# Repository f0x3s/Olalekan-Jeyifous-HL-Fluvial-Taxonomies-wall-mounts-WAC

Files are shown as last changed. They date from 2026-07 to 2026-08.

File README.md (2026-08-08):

# Olalekan Jeyifous Fluvial Taxonomies Wall Mounts

<p align="center">
  batch of mounts epoxied to sculptures
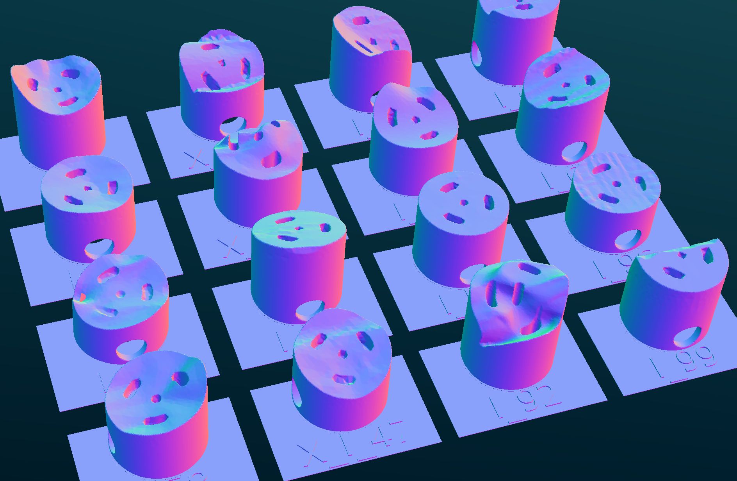
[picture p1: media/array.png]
array of processed mount meshes
  
</p>

A programmatic approach to generating 40 unique wall mounts for Olekelan Jeyifous' sculpture series: *Fluvial Taxonomies* as part of [*Hydrocosmic Litanies*](https://www.walkerart.org/whats-on/olalekan-jeyifous-hydricosmic-litanies/), his solo exhibition at the Walker Art Center.

This repository contains the editable mount files with their exported meshes, final print-ready STLs, and the batch-processing workflow used to center, identify, thermally compensate, and repair each mount before printing.

*__This repository does not contain any artwork meshes or original artist files__*

## Files
Fabrication files and processing tools for the wall-mount system.
> 📂 **[3d-files](3d-files)/** — *source mount geometry*<br>
> - 📁 [`isolated-mount-meshmixer`](3d-files/isolated-mount-meshmixer)/ — *editable Meshmixer project files*
> - 📁 [`isolated-mount-export`](3d-files/isolated-mount-export)/ — *exported STL files used as processing inputs*
>
> 📂 **[ready-for-print](ready-for-print)/** — *processed and repaired print files*<br>
> - 📁 [`printed`](ready-for-print/printed)/ — *completed mounts retained for print tracking*
> - 🧊 [`insert.stl`](ready-for-print/insert.stl) — *generated insert puck*
>
> 📂 **[scripts](scripts)/** — *Python and OpenSCAD processing tools*<br>
> - 🐍 [`batch_process_ft_mounts.py`](scripts/batch_process_ft_mounts.py) — *main batch-processing script*
> - ⚙️ [`batch_openscad.scad`](scripts/batch_openscad.scad) — *combined label and thermal-compensation operation*
> - ⚙️ [`generate_label.scad`](scripts/generate_label.scad) — *standalone label generator used by the fallback process*
> - ⚙️ [`label_module.scad`](scripts/label_module.scad) — *label and brim geometry*
> - ⚙️ [`thermal_expansion_ring.scad`](scripts/thermal_expansion_ring.scad) — *thermal-expansion compensation cutting geometry*
> - ⚙️ [`insert.scad`](scripts/insert.scad) — *insert puck geometry*

## Background and File Preproduction

Installing *Fluvial Taxonomies* presented several technical challenges. The resin-printed sculptures are fragile, with highly detailed surfaces and no preordained mounting points nor provisions for hardware. The piece is intended to be shown as groupings of objects mounted offset from the walls in the gallery. I determined that the best way to hang them was a custom 3d-printed mount per-object, secured to the sculpture with specialty plastic epoxy. These mounts are created from duplicates of a standard base geometry, pictured below, that each have a sculpture digitally subtracted from them:

<p align="center">
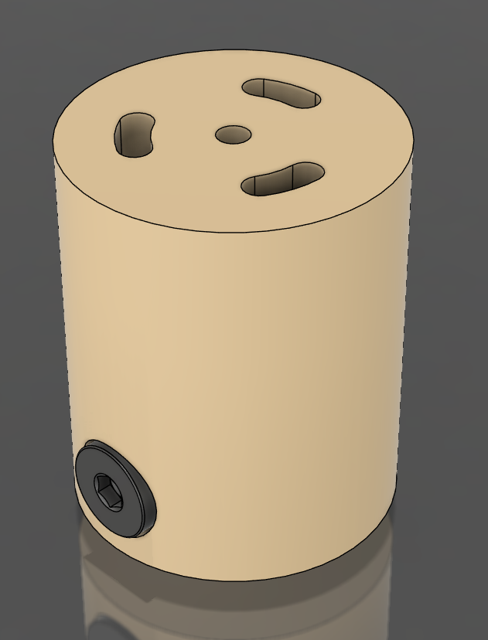
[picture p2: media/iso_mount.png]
iso view of base mount geometry
  
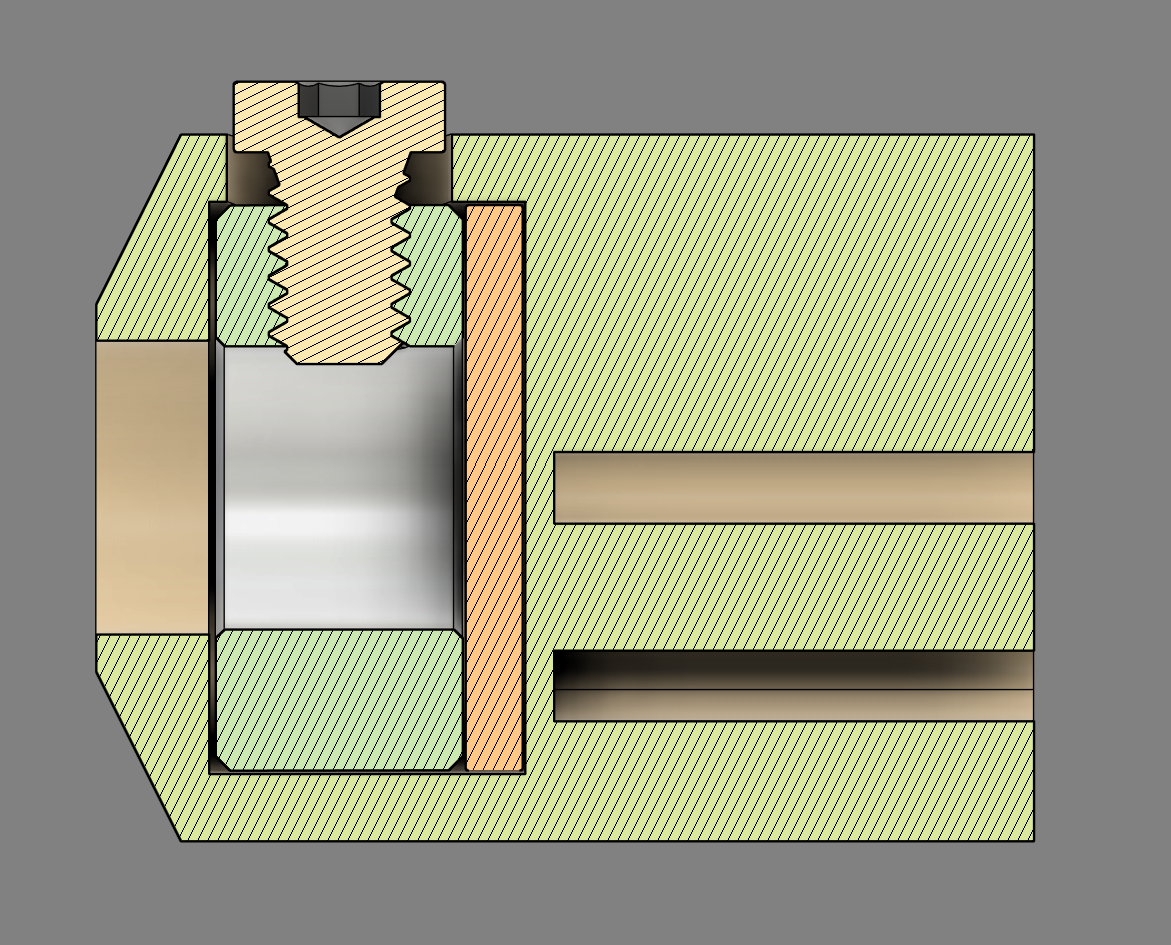
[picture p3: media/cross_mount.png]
base mount geometry cross sectional analysis
  
</p>

The inserted shaft collar *([McMaster: 9946K15](https://www.mcmaster.com/9946K15/))* allows for strong coupling to wall-mounted rods, and the low-profile machine screw *([McMaster: 92220A182](https://www.mcmaster.com/92220A182/))* arrests rotation inside the mount. The axial channels provide space for epoxy to seep into the structure for a mechanically strong bond.

<p align="center">
  recording physical dimensions asst. Prerna
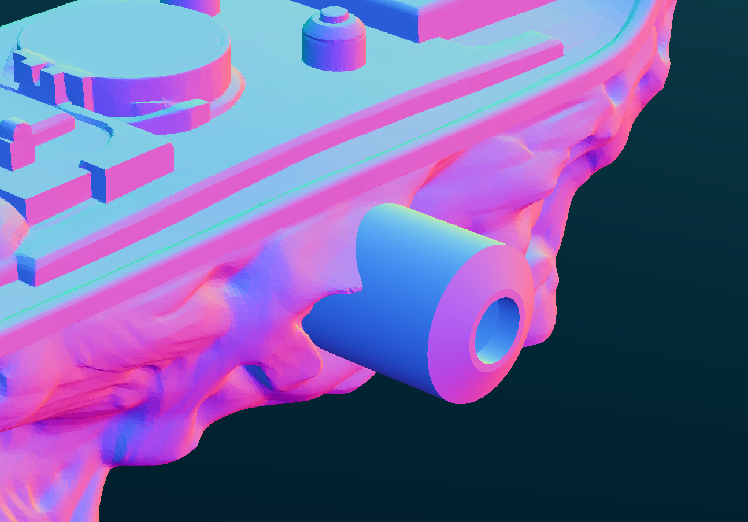
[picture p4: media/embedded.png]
mount geometry embedded in sculpture mesh
  
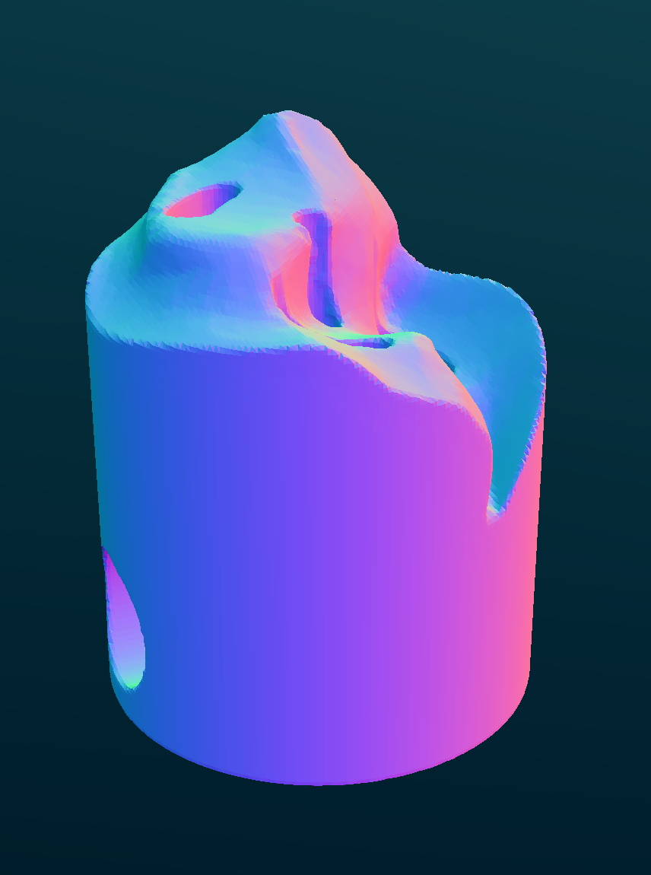
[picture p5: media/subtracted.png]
sculpture mesh subtracted from mount geometry
  
</p>

The next step was to scale the sculpture models, virtually place the mounts, and perform the Boolean operations. The artist-provided sculpture mesh files were not consistently scaled, so an extent measurement was taken from the physical piece and used to correctively transform the file. Then, a copy of the mount geometry was manually oriented against it, with as much of the region beyond the start of the epoxy channels intersecting the sculpture geometry as possible. The sculpture was subtracted from the mount, and the mount was re-oriented axially along the z-axis (without regard to its position in world space), before being made watertight and exported as a stereolithography file.

Meshmixer was chosen to perform these operations as it was the most lightweight tool that could consistently load the meshes and successfully perform the Boolean. Other programs either lacked the ability to both manipulate and view the mesh efficiently, or failed to perform the subtraction due to the number of mesh degeneracies in the sculpture files.

## Script Behavior

For each STL in `3d-files/isolated-mount-export`, the batch-processing script:

1. Centers the mesh on the x/y origin and places its base on the z=0 plane.
2. Generates an identification label from the source filename and joins it to the mount.
3. Subtracts a compensation tool around the insert region to reduce bulging at the transition between printed density regions. This tool also clearances the shaft collar void slightly to correct for mesh warping in Boolean process.
4. Exports the completed model to `ready-for-print` using the suffix `_for-print.stl`.
5. Repairs the completed STL with ADMesh.

The script first attempts to perform the label union and compensation cut as a single OpenSCAD operation. If OpenSCAD cannot process the imported mesh, it falls back to separate `stl_cmd` boolean operations for non-manifold geometry.

A matching file placed in `ready-for-print/printed` is treated as complete and will be skipped during later runs.

Additionally, the script generates an 'insert puck'. This is placed on top of the shaft collar to eliminate need for bridging over the center hole.

## Requirements

- Python 3
- OpenSCAD, available as `openscad` in the system PATH
- ADMesh, available as `admesh` in the system PATH
- `stl_cmd` by AllwineDesigns, including `stl_zero` and `stl_boolean` in the system PATH

*Recommended .stl viewer: [fstl](https://github.com/fstl-app/fstl)*

## Usage

Run the batch processor from the repository root:

```bash
python3 scripts/batch_process_ft_mounts.py
```

New source files exported from meshmixer should be placed in:

```text
3d-files/isolated-mount-export/
```

Completed files will be written to:

```text
ready-for-print/
```

The source filename is carried through the workflow and used for both the identification label and final output filename. Move a verified print into `ready-for-print/printed` to prevent it from being regenerated during subsequent batch runs.

## Printing

I printed the mounts and insert pucks on a Prusa MK4 using PETG. Layer height was set to `0.15mm STRUCTURAL` with 30% infill. A pause command was inserted into the G-Code at layer 126 (18.89mm) so that the shaft collar and insert puck may be placed into the print.

<p align="center">
  beginning of mount print at pause point.
  collar placed
  puck placed- print resumes here
</p>

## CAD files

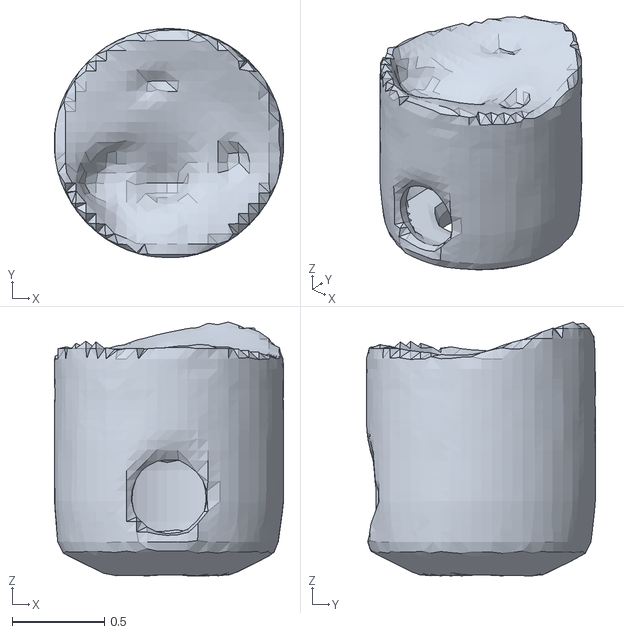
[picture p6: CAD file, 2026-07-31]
3d-files/isolated-mount-export/I_17.stl
1.25 x 1.24 x 1.38

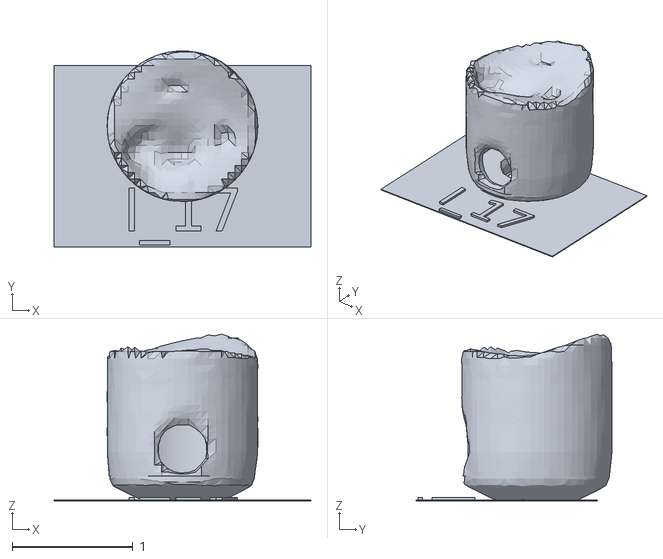
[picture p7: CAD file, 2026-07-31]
ready-for-print/printed/I_17_for-print.stl
2.12 x 1.62 x 1.38

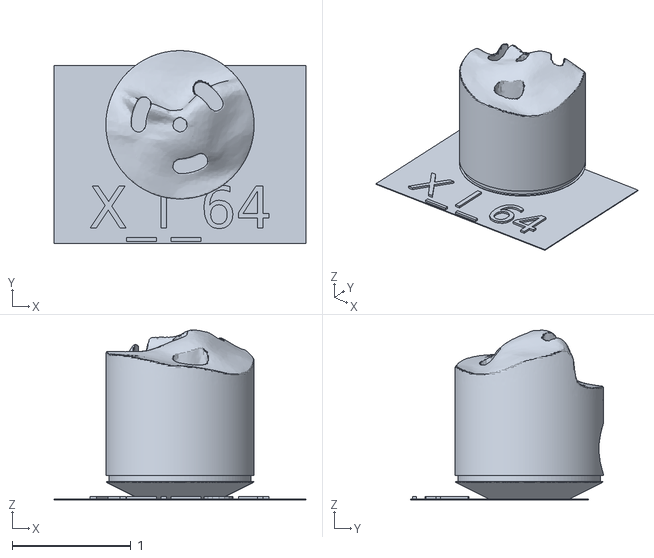
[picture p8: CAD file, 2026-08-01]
ready-for-print/X_I_64_for-print.stl
2.12 x 1.62 x 1.43

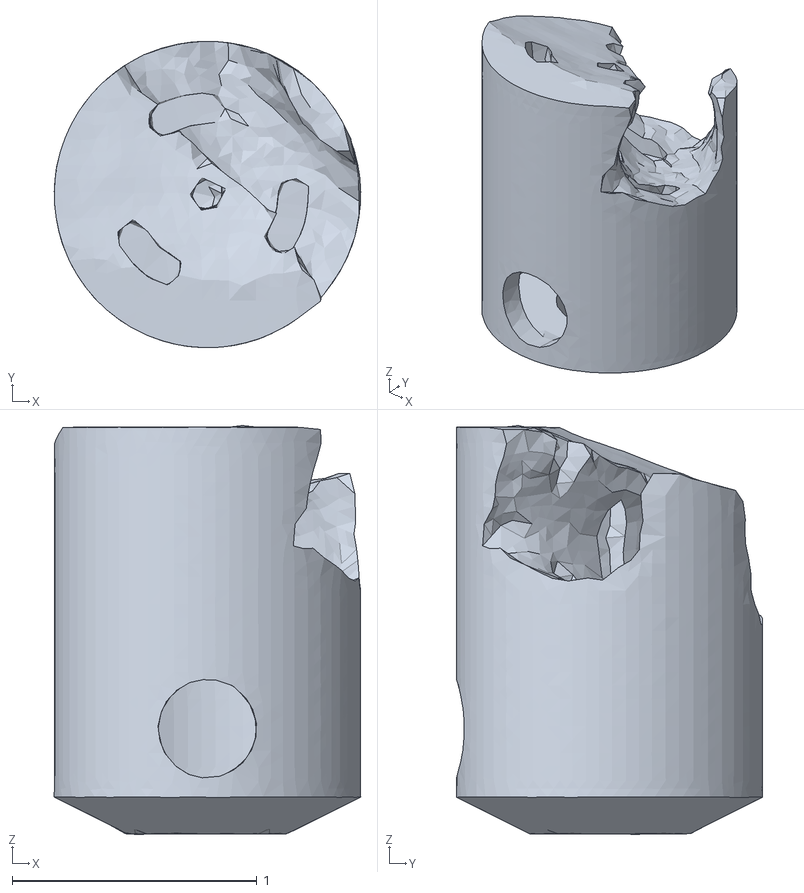
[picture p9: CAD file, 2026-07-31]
3d-files/isolated-mount-export/I_19.stl
1.25 x 1.25 x 1.67

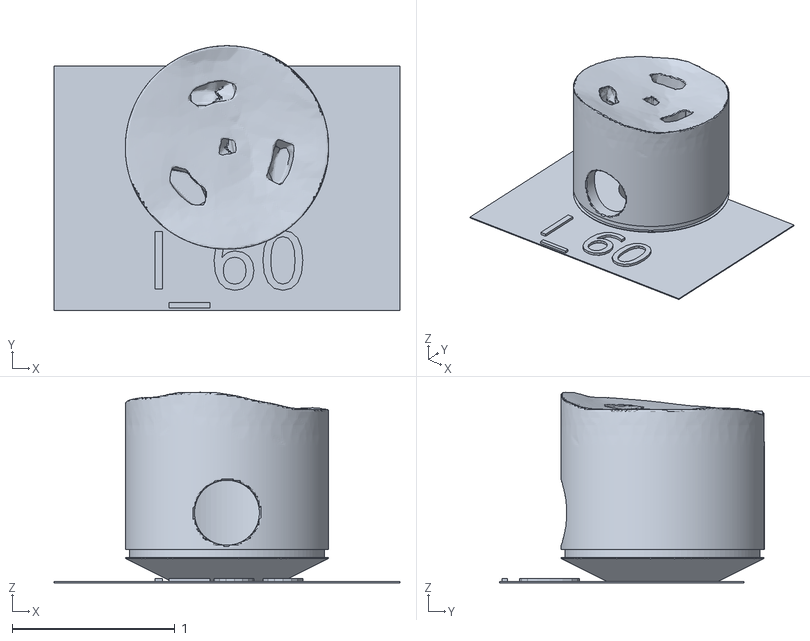
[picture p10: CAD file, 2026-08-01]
ready-for-print/I_60_for-print.stl
2.12 x 1.62 x 1.17

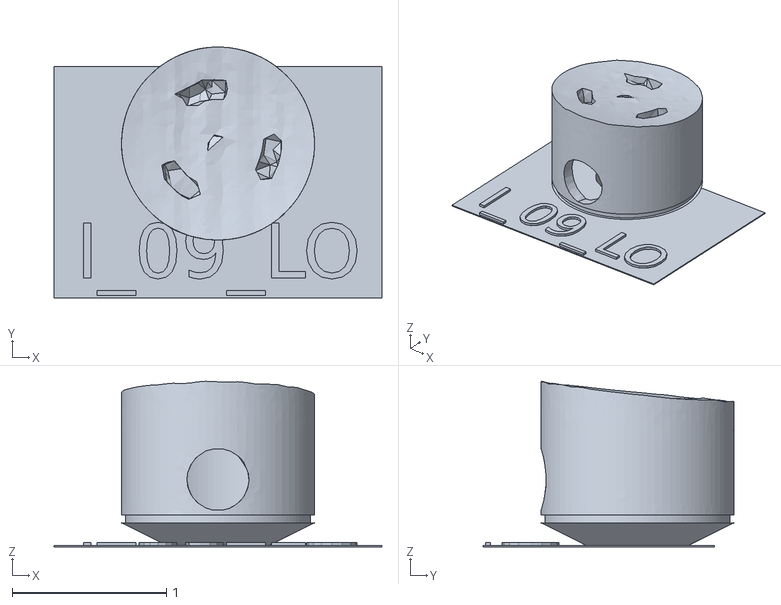
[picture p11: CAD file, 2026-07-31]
ready-for-print/printed/I_09_LO_for-print.stl
2.12 x 1.63 x 1.07

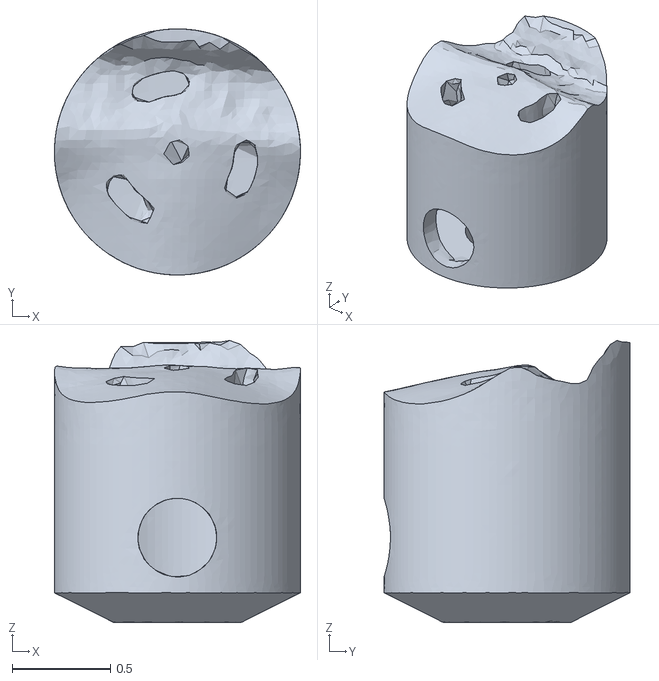
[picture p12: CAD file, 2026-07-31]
3d-files/isolated-mount-export/B_14_LO.stl
1.25 x 1.25 x 1.43

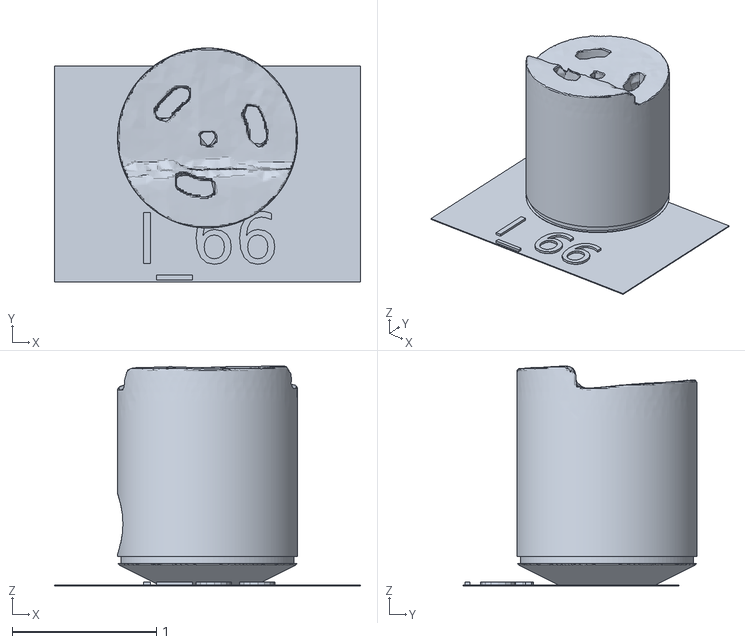
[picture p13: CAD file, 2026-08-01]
ready-for-print/I_66_for-print.stl
2.12 x 1.62 x 1.53

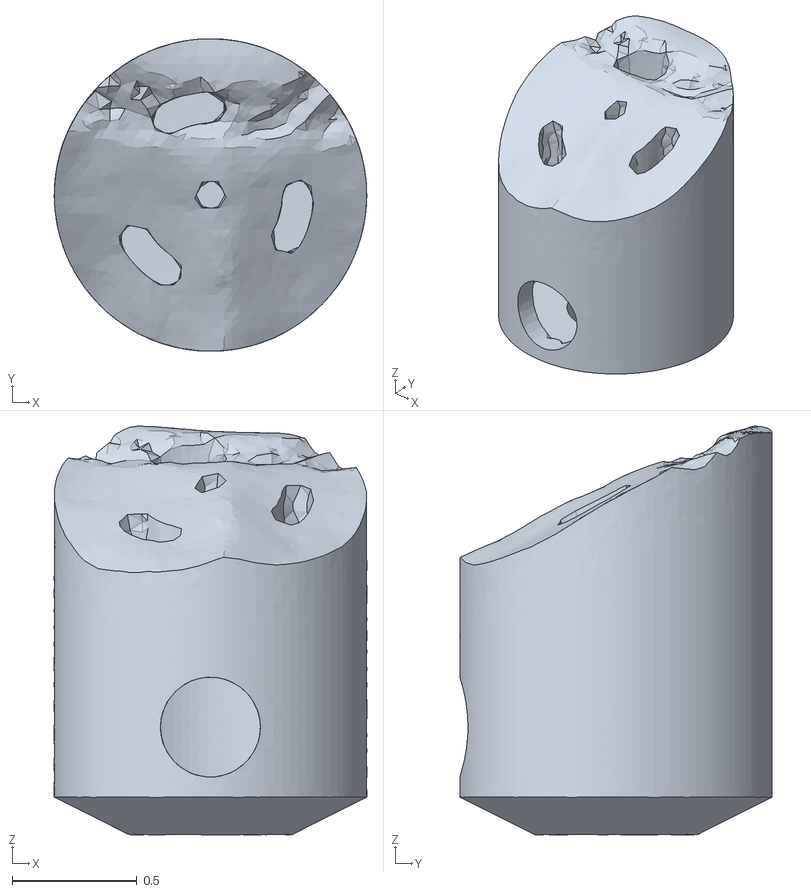
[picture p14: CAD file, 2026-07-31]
3d-files/isolated-mount-export/B_17_LO.stl
1.25 x 1.25 x 1.64

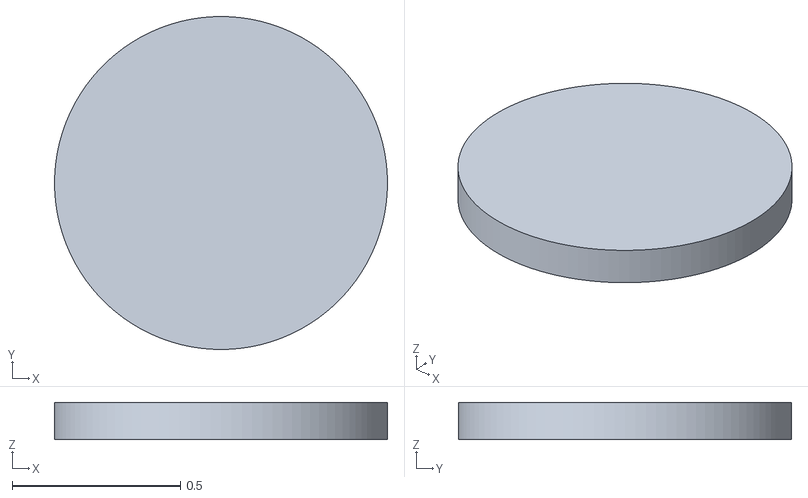
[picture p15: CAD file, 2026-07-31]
ready-for-print/insert.stl
0.99 x 0.99 x 0.111

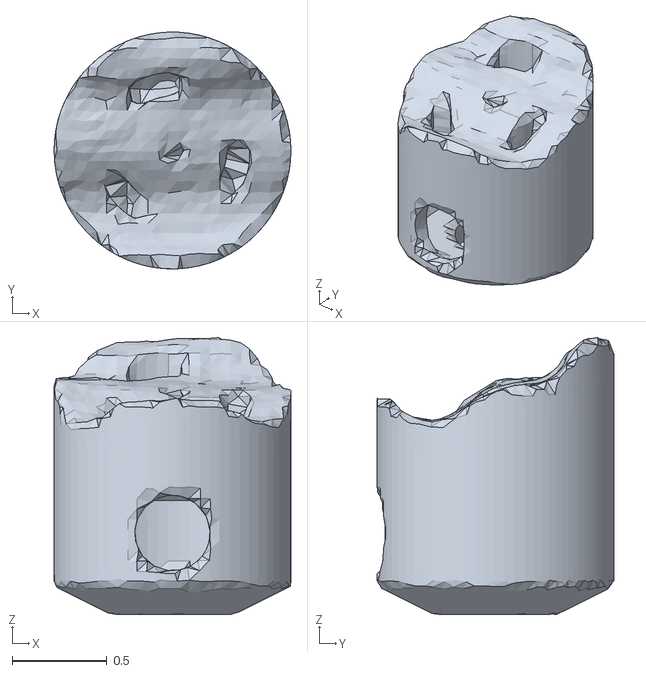
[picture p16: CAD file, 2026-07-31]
3d-files/isolated-mount-export/B_18_LO.stl
1.25 x 1.25 x 1.46

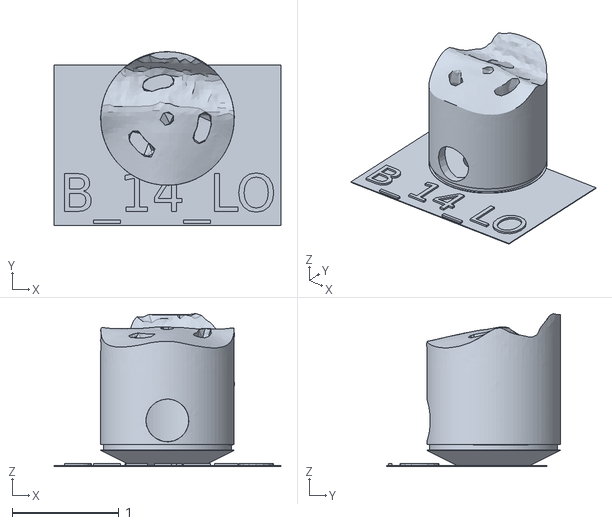
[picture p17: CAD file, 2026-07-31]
ready-for-print/printed/B_14_LO_for-print.stl
2.12 x 1.63 x 1.43

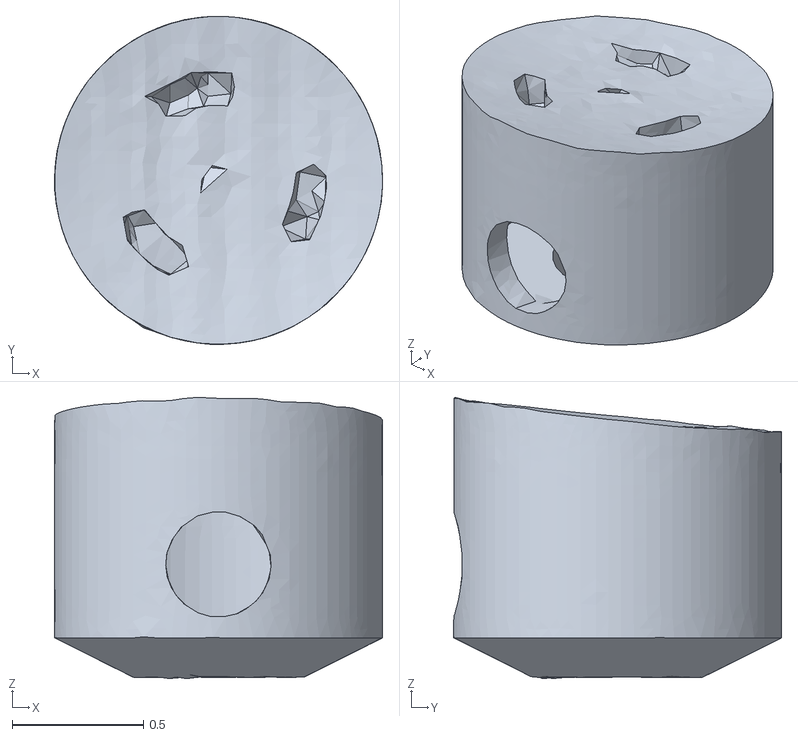
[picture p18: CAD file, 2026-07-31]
3d-files/isolated-mount-export/I_09_LO.stl
1.25 x 1.25 x 1.07

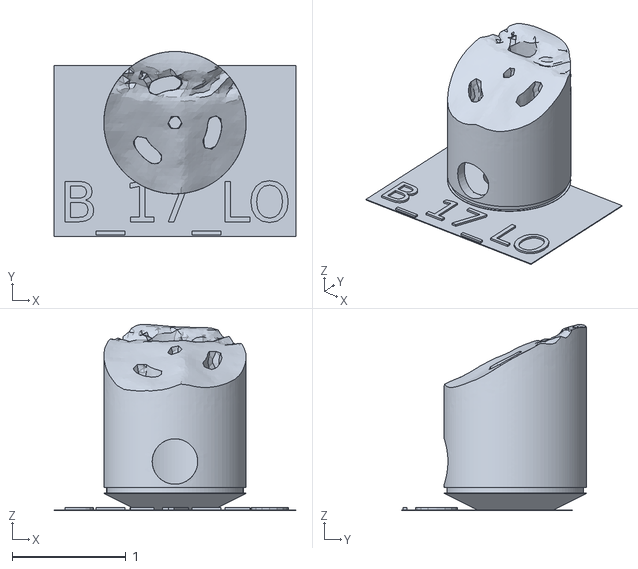
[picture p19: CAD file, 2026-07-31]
ready-for-print/printed/B_17_LO_for-print.stl
2.12 x 1.63 x 1.64

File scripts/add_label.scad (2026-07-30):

label_text = "";

mm_to_in = 0.03937805;
layer_height = .2 * mm_to_in;

text_size = 0.35;
text_height = layer_height * 3;
text_x = 0;
text_y = -.75;

union() {
    translate([text_x, text_y, layer_height])
        linear_extrude(height = text_height)
            text(
                label_text,
                size = text_size,
                halign = "center",
                valign = "center"
            );
    
    difference() {
        translate([0, -0.25, 1 * layer_height])
            cube([2.125, 1.5, layer_height], center = true);
        translate([0, 0, layer_height])
            cylinder(height = layer_height, r = 0.34, $fn = 100, center = true);
    }
}

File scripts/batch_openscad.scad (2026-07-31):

model_file = "";
expansion_ring = "";
label_text = "";

mm_to_in = 0.03937805;
layer_height = .2 * mm_to_in;

text_size = 0.35;
text_height = layer_height * 3;
text_x = 0;
text_y = -.75;

module label() {
    include <label_module.scad>;
}

difference() {
    union() {
        import(model_file, convexity=10);
        label();
    }
    
    import(expansion_ring, convexity=10);
}

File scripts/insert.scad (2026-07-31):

translate([0,0,.1105/2])
    cylinder(h=.1105, r=.495, $fn=100, center = true);

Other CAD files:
ready-for-print/printed/I_21_for-print.stl
ready-for-print/printed/B_10_LO_for-print.stl
3d-files/isolated-mount-export/B_10_LO.stl
ready-for-print/printed/I_19_for-print.stl
scripts/generate_label.scad
3d-files/isolated-mount-export/I_21.stl
scripts/label_module.scad
scripts/speculative_v2_base_mount_geometry.scad
scripts/thermal_expansion_ring.scad

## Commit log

2026-07-30 added batch 1 isolated mounts + stl exports
    [B_10_LO.stl, B_14_LO.stl, B_17_LO.stl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]
2026-07-30 test center
    [B_10_LO.stl, B_14_LO.stl, B_17_LO.stl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]
2026-07-30 label gen .scad
    [add_label.scad]
2026-07-30 fixed ascii to binary stl error
    [B_10_LO.stl, B_14_LO.stl, B_17_LO.stl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]
2026-07-30 density threshold thermal expansion compensation
    [B_10_LO.stl, B_14_LO.stl, B_17_LO.stl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]
2026-07-31 began script merge
    [generate_label.scad]
2026-07-31 added stl repair stage & adjusted thermal comp
    [thermal_expansion_ring.scad]
2026-07-31 refactor dirs
    [B_10_LO.stl, B_10_LO_for-print.stl, B_14_LO.stl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]
2026-07-31 moved to pymeshfix
    [B_10_LO_for-print.stl, B_14_LO_for-print.stl, B_17_LO_for-print.stl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]
2026-07-31 reverted to admesh
    [B_10_LO_for-print.stl, B_14_LO_for-print.stl, B_17_LO_for-print.stl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]
2026-07-31 center cut
    [B_10_LO_for-print.stl, B_14_LO_for-print.stl, B_17_LO_for-print.stl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]
2026-07-31 updated tolerances
    [B_10_LO_for-print.stl, B_14_LO_for-print.stl, B_17_LO_for-print.stl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]
2026-07-31 remeshed with new tolerance
    [B_10_LO_for-print.stl, B_14_LO_for-print.stl, B_17_LO_for-print.stl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]
2026-07-31 updated printed folder
    [B_17_LO_for-print.stl, I_09_LO_for-print.stl, I_19_for-print.stl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]
2026-07-31 exlcude already printed files
    [B_18_LO_for-print.stl, thermal_expansion_ring.scad]
2026-07-31 begin opnscad refactor
    [B_10_LO.stl, B_14_LO.stl, B_17_LO.stl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]
2026-07-31 merged openscad processes
    [B_18_LO_for-print.stl, batch_openscad.scad, thermal_expansion_ring.scad]
2026-07-31 added fallback mesh procedure
    [generate_label.scad]
2026-07-31 modularized label generation
    [batch_openscad.scad, generate_label.scad, label_module.scad]
2026-07-31 second batch of exports
    [I_17.stl]
2026-07-31 clear exports
    [B_18_LO_for-print.stl, insert.stl]
2026-07-31 adjusted tolerance
    [thermal_expansion_ring.scad]
2026-07-31 process all mounts for printing
    [I_17_for-print.stl, I_60_for-print.stl, I_66_for-print.stl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]
2026-08-01 Friday prints
    [I_17_for-print.stl]
2026-08-01 rerendered with new tolerances
    [I_60_for-print.stl, I_66_for-print.stl, X_I_64_for-print.stl]
